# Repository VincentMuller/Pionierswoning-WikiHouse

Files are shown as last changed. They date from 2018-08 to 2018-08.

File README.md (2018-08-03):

# Pionierswoning-WikiHouse
First built WikiHouse as a test and showcase (finished feb. 2018) for the 20 WikiHouses project in Almere, Netherlands.
Started with the WREN system (as used in the MicroHouse) and changed it to a new system called SWIFT. Where WREN has a maximum span at 3,6 m is the span of SWIFT to 4,8 m. (WREN is more flexible for making window and door openings, SWIFT is more flexible in interior space) 

The files are updated with minor changes to (version 2) the WikiHouse chassis of the Pionierswoning, containing:
- Manual (pdf) with instructions how to build,
- CAD file (dxf) including all the parts for CNC-cutting,
- 3d Sketchup files (skp), including finishing materials inside and outside,
- Pictures of the construction as an extra help
- Calculations of the structural engineer
- And may be more to come later...

VERY IMPORTANT:
Find a structural engineer to do or check the calculations for fitting to local circumstances, laws and regulations.
Building this house is always on your own responsibility! 

Terms of use

By downloading these files or information you agree to the following terms and conditions.

Information is shared without any kind of warranty or guarantee All Information is provided ‘as is’. No representations or warranties express or implied are made regarding the Wikihouse Info, its accuracy, completeness, functionality or fitness for a particular use in a particular location.

You are solely responsible for the use of the information By using this information you assume full responsibility for any loss resulting from use or inability to use the Wikihouse Info, and forever releases WikiHouse Foundation or other WikiHouse users from any liability for such loss; including but not limited to loss of profits, goodwill or assets.

You are responsible for meeting local codes and legislation Users must satisfy themselves regarding the application of statutory requirements, local building regulations, codes, insurance certification or other requirements or recommendations relevant to the location where and materials with which they plan to build. Where required you should always seek the advice of a relevant qualified professional.

You are responsible for using the information in a safe way Users are responsible for ensuring that information they use or cause to be used is used in a way which is safe, and is not likely to cause harm during or after manufacturing, construction, use or disassembly.

Creative Commons License

<br />This work is licensed under a <a rel="license" href="http://creativecommons.org/licenses/by-sa/4.0/">Creative Commons Attribution-ShareAlike 4.0 International License</a>.

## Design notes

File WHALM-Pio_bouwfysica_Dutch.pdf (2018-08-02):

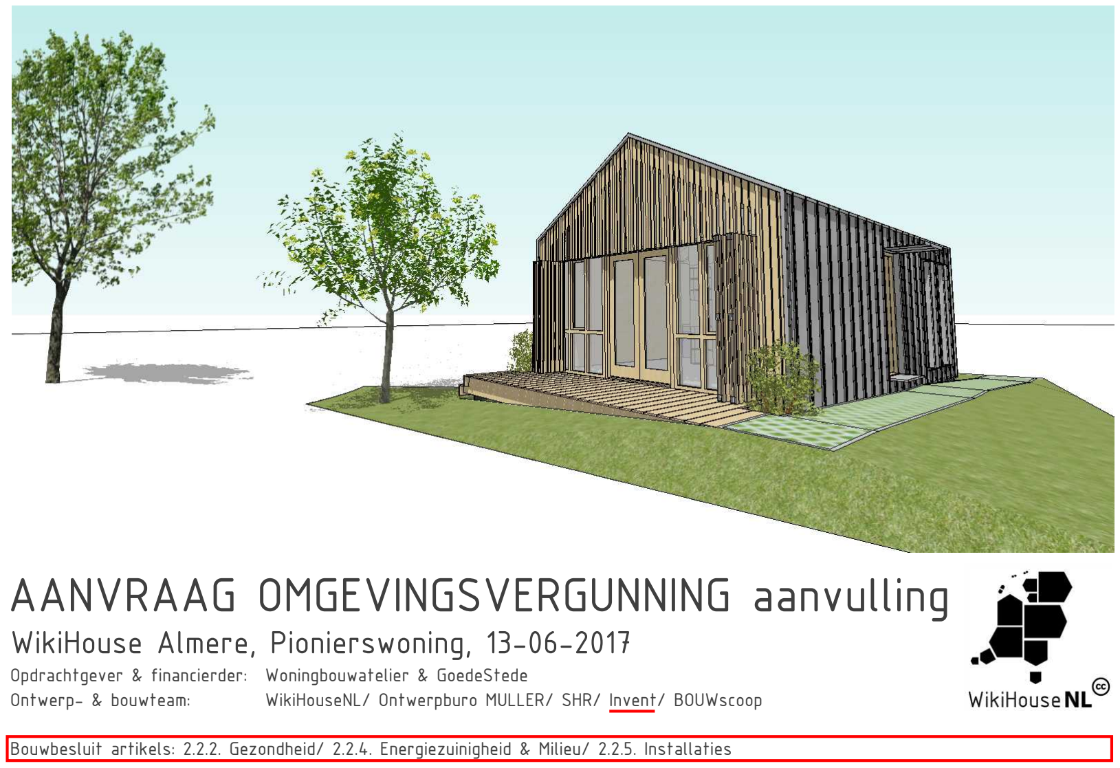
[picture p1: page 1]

# WikiHouse Almere, Pionierswoning, 13-06-2017

### Opdrachtgever & financierder: Woningbouwatelier & GoedeStede

Ontwerp- & bouwteam: | WikiHouseNL/ Ontwerpburo MULLER/ SHR/ Invent/ BOUWscoop

Bouwbesluit artikels: 2.2.2. Gezondheid/ 2.2.4. Energiezuinigheid & Milieu/ 2.2.5. Installaties

# AANVRAAG OMGEVINGSVERGUNNING aanvulling

## MEMO

Projectnummer: 16-526 | Projectnaam: WikiHouse Almere
Datum: 13 juni 2017 | Opsteller(s): E. Giesen
Onderwerp | : Verankering spant

### 1. Bouwfysische beoordeling

### 1.1. Toelichting

In onderstaande detailtekening is de verankering van de spanten zichtbaar door de vloerplaat op de HE140A funderingsbalk. Om te beoordelen of de bevestiging van de ankers condensatieproblemen kunnen veroorzaken is het detail in een 3D model uitgewerkt en doorgerekend (Trisco software). De afwerking van zowel de buitenzijde als de binnenzijde is hierbij achterwege gelaten, deze hebben geen invloed op de berekening van de f-factor (temperatuurfactor).

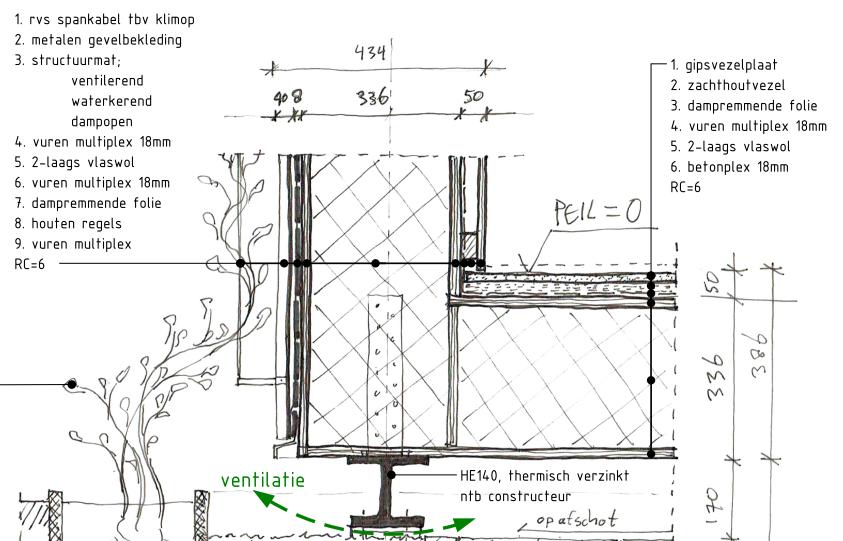
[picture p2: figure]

- Voor dit detail is een f-factor bepaald van 0,918. Dit voldoet aan het Bouwbesluit.

## MEMO

Projectnummer: 16-526 | Projectnaam: WikiHouse Almere
Datum: 13 juni 2017 | Opsteller(s): E. Giesen

### 1.2. Rekenresultaten Trisco

TRISCO - Rekenresultaten

TRISCO gegevensbestand: Detail verankering 20170613.trc

Aantal knooppunten = 1563504
Warmtedivergentie voor totaal object = 0.000852355
Warmtedivergentie voor meest nadelige knoop = 0.16967
Klr. Type | Naam | tmin | X | Y | Z | tmax | X | Y | Z
| | | [°C] | | | | [°C] | | | _
11 | MATERIAL | stainless steel | 0.06 | 61 | 15 | 100 | 3.37 | 71 | 71 | 42
13 | MATERIAL | steel | 0.02 | 77 | 1 | 0 | 0.07 | 58 | 26 | 27
41 | MATERIAL | PVC rigid | 14.80 | 127 | 81 | 57 | 19.65 | 128 | 114 | 122
60 | MATERIAL | EPDM | 0.02 | 35 | 27 | 0 | 0.14 | 58 | 29 | 27
131 | MATERIAL | insulation 0.04 | 0.01 | 11 | 39 | 2 | 19.35 | 117 | 114 | 0
137 | MATERIAL | cement-bonded p | 0.00 | 11 | 29 | 120 | 0.70 | 64 | 39 | 41
139 | MATERIAL | plywood 700 kg/ | 0.00 | 1 | 29 | 2 | 19.63 | 127 | 114 | 122
145 | MATERIAL | gypsum 1200 kg/ | 17.87 | 128 | 94 | 65 | 19.70 | 142 | 102 | 122
155 | MATERIAL | insulation 0.04 | 14.83 | 129 | 82 | 65 | 19.63 | 142 | 94 | 122
170 | BC_SIMPL | exterior | 0.00 | 1 | 29 | 2 | 0.18 | 1 | 114 | 50
174 | BC_SIMPL | interior (norma | 18.36 | 128 | 102 | 56 | 19.70 | 142 | 102 | 122
Klr. Type | Naam | ta | Flux in | Flux uit
| | | [°C] | | [W] | | [W]
170 | BC_SIMPL | exterior | 0.00 | 1.96
174 | BC_SIMPL | interior (norma | 1.96 | 0.00

Temperatuurfactor (EN ISO 10211) = 0.918
hi = 7.70 W/(m².K)
Rsi = 0.13 m².K/W
Oppervlaktecondensatie als RV > 90 % (bij 20.00°C)

## MEMO

Projectnummer: 16-526 | Projectnaam: WikiHouse Almere
Datum: 13 juni 2017 | Opsteller(s): E. Giesen

### 1.3. Afbeeldingen simulatiemodel

Afbeelding 1. Zijaanzicht materiaal en ʎ-waarden [2D]

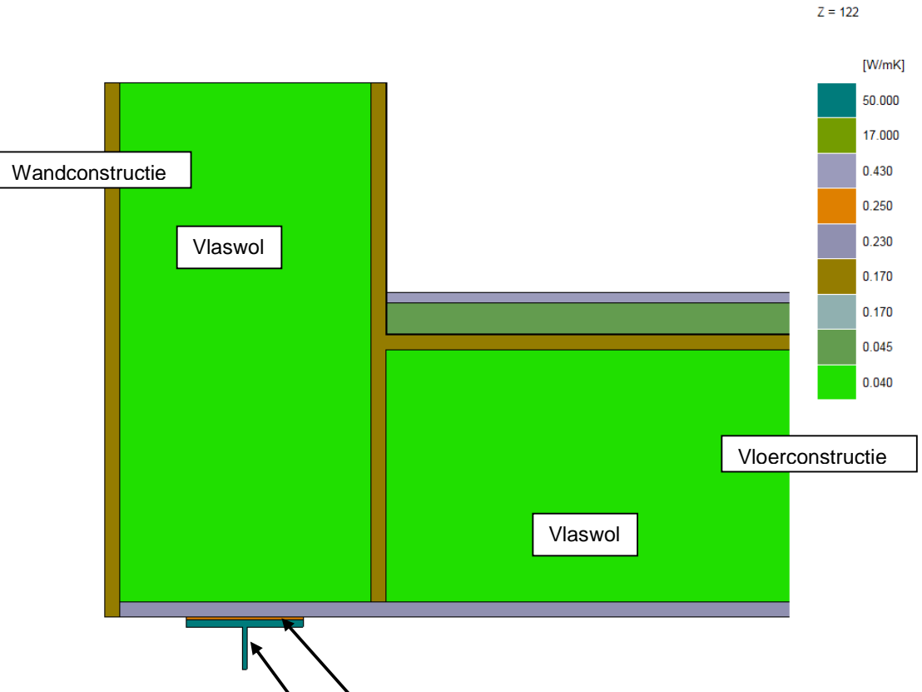
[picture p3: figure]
Vlaswol; Wandconstructie; Vloerconstructie

HE140A balk
(deels)

Neopreen

## MEMO

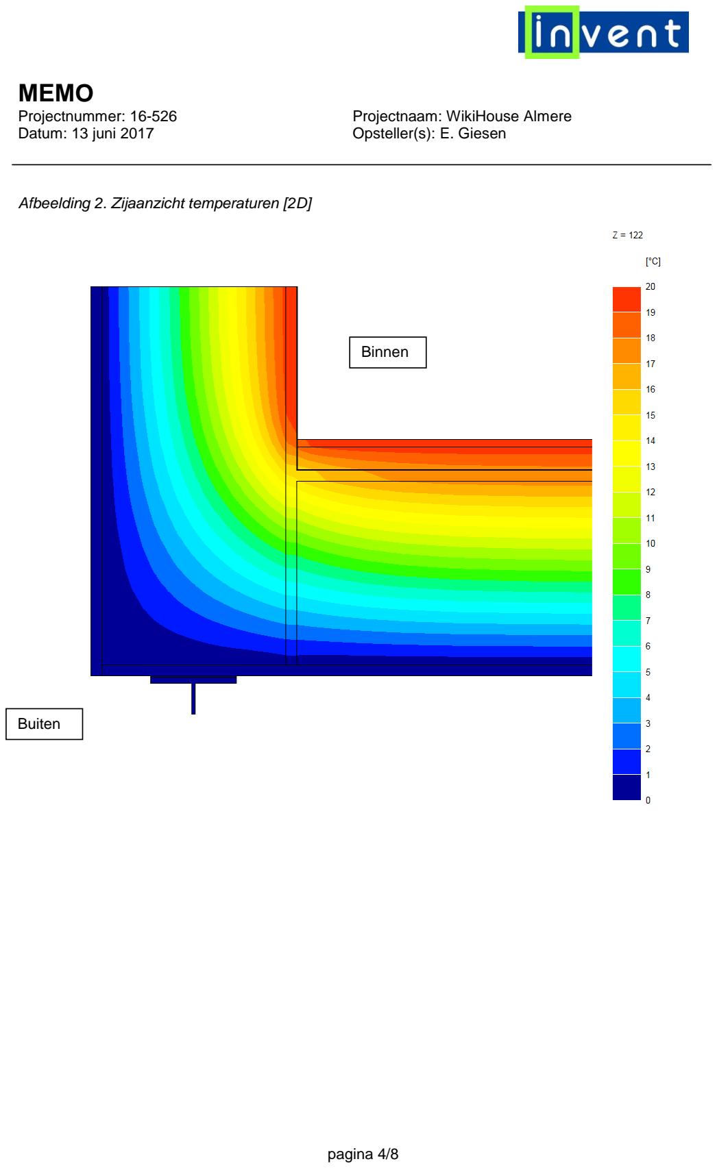
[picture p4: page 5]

Projectnummer: 16-526 | Projectnaam: WikiHouse Almere
Datum: 13 juni 2017 | Opsteller(s): E. Giesen

Afbeelding 2. Zijaanzicht temperaturen [2D]

Binnen

Buiten

## MEMO

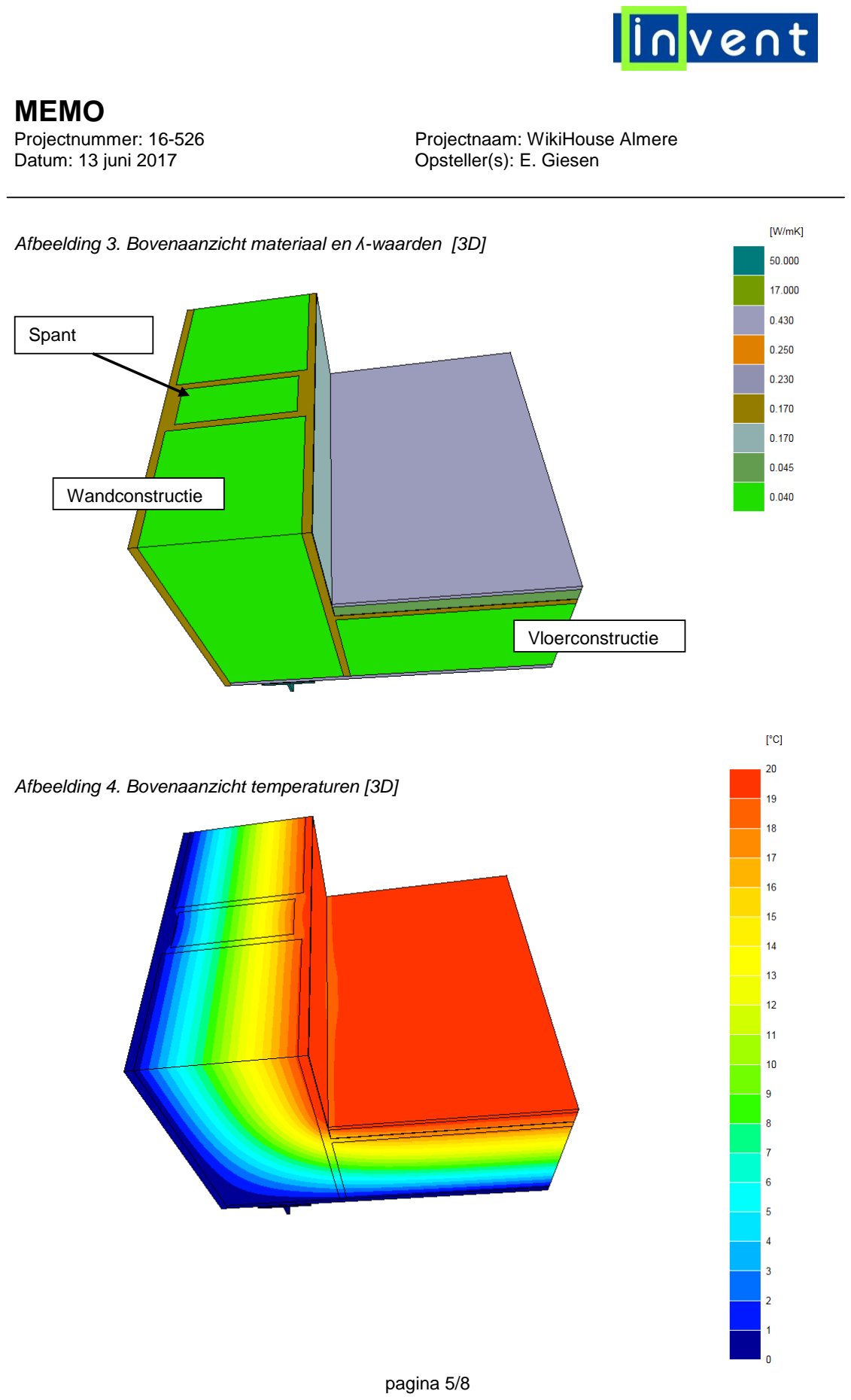
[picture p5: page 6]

Projectnummer: 16-526 | Projectnaam: WikiHouse Almere
Datum: 13 juni 2017 | Opsteller(s): E. Giesen

Afbeelding 3. Bovenaanzicht materiaal en ʎ-waarden [3D]

Afbeelding 4. Bovenaanzicht temperaturen [3D]

Spant

Wandconstructie

Vloerconstructie

## MEMO

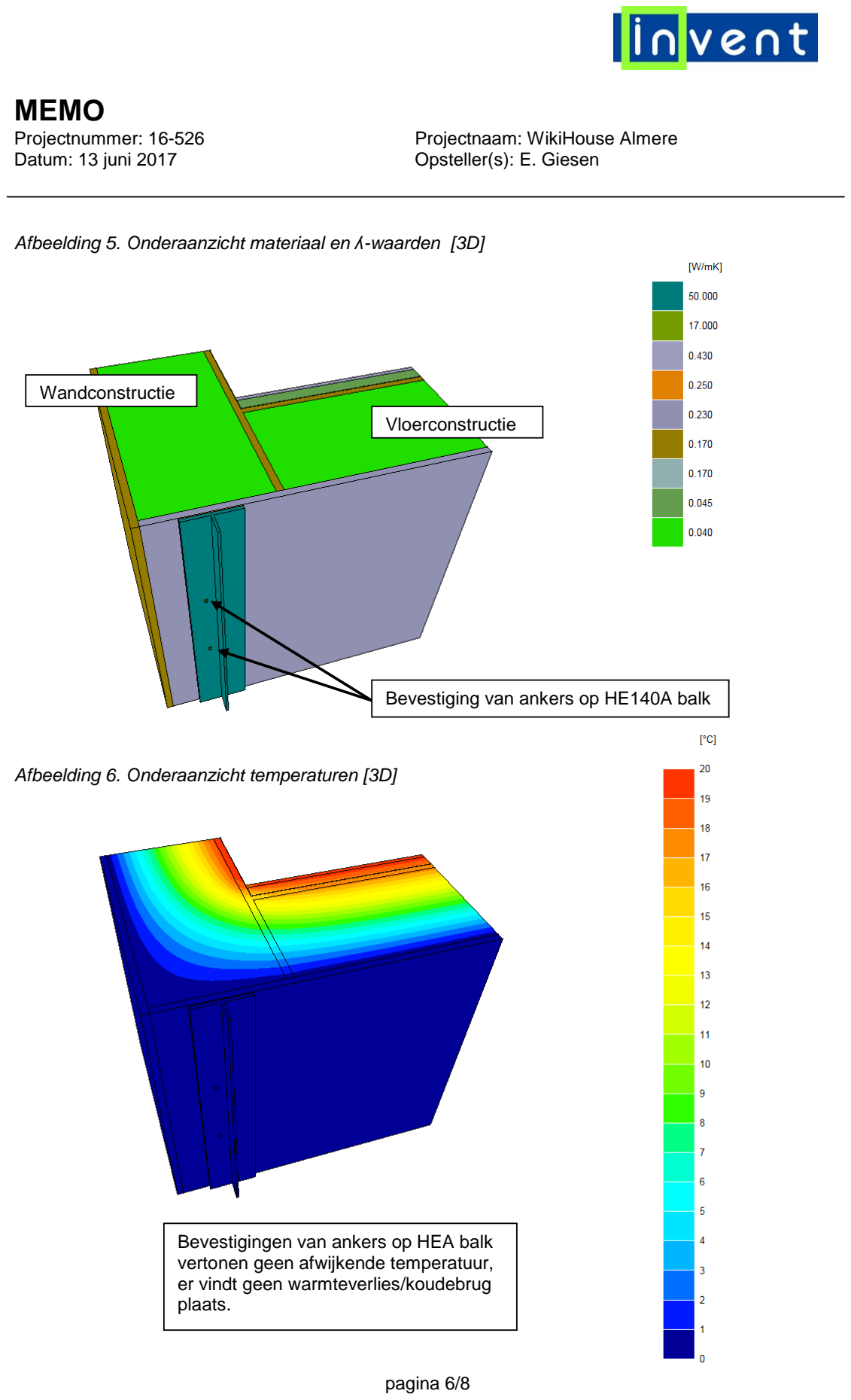
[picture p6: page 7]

Projectnummer: 16-526 | Projectnaam: WikiHouse Almere
Datum: 13 juni 2017 | Opsteller(s): E. Giesen

Afbeelding 5. Onderaanzicht materiaal en ʎ-waarden [3D]

Afbeelding 6. Onderaanzicht temperaturen [3D]

Bevestiging van ankers op HE140A balk

Bevestigingen van ankers op HEA balk vertonen geen afwijkende temperatuur, er vindt geen warmteverlies/koudebrug plaats.

Wandconstructie

Vloerconstructie

## MEMO

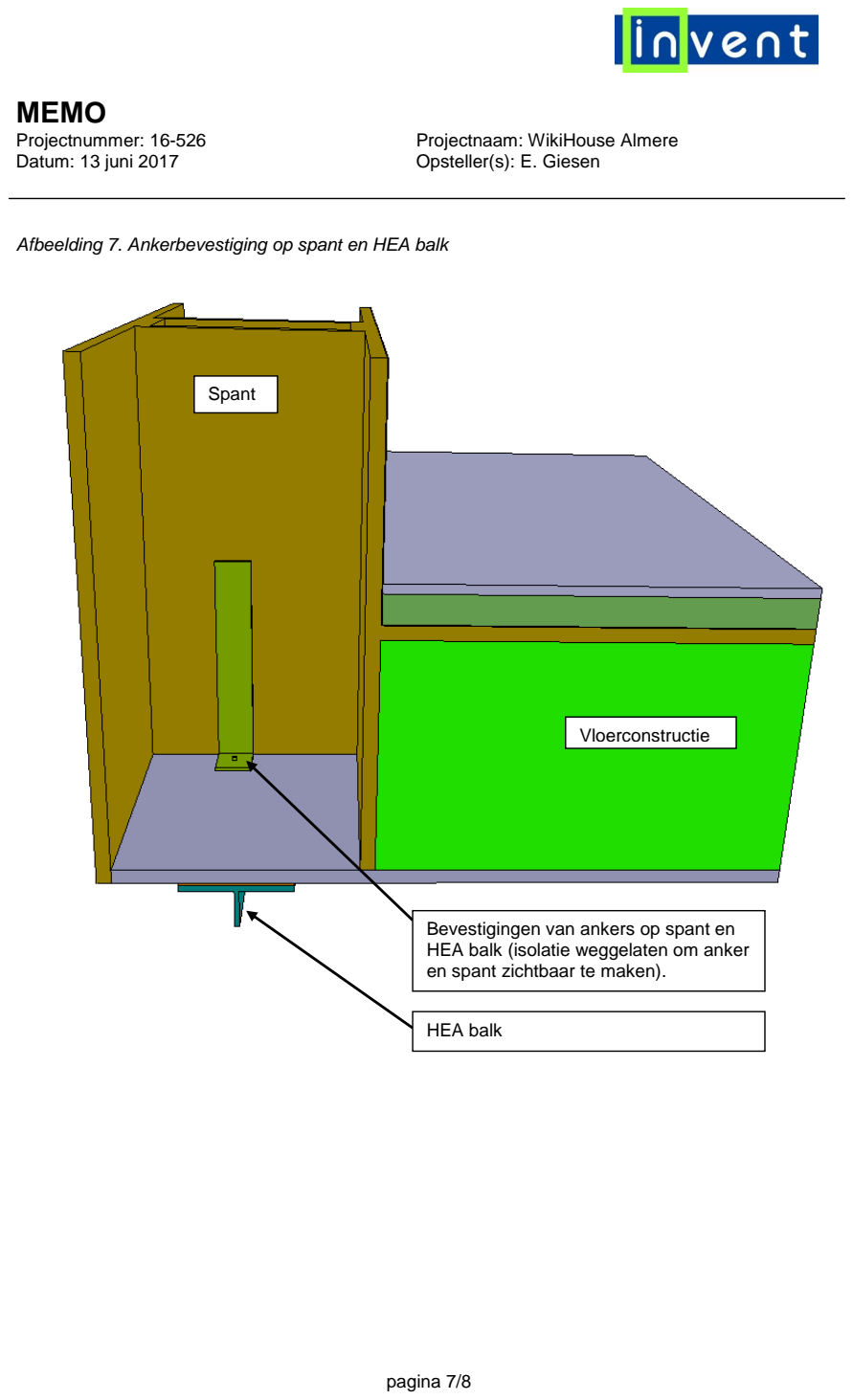
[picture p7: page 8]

Projectnummer: 16-526 | Projectnaam: WikiHouse Almere
Datum: 13 juni 2017 | Opsteller(s): E. Giesen

Afbeelding 7. Ankerbevestiging op spant en HEA balk

Bevestigingen van ankers op spant en HEA balk (isolatie weggelaten om anker en spant zichtbaar te maken).

HEA balk

Spant

Vloerconstructie

## MEMO

Projectnummer: 16-526 | Projectnaam: WikiHouse Almere
Datum: 13 juni 2017 | Opsteller(s): E. Giesen

Afbeelding 8. Bovenaanzicht ankerbevestiging op spant

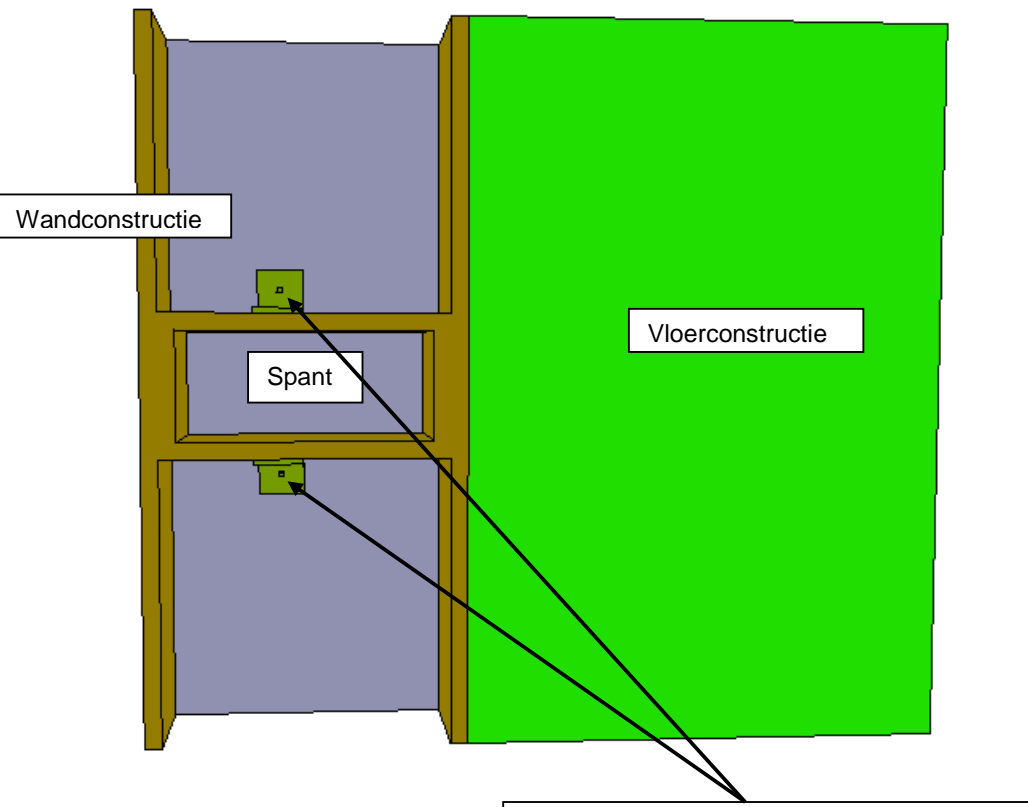
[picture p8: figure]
Spant; Vloerconstructie; Wandconstructie

Bevestigingen van ankers aan beide zijde op het spant (isolatie weggelaten om ankers en spant zichtbaar te maken).

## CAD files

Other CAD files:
Whalm-Pio_v2_CNC-parts.dxf

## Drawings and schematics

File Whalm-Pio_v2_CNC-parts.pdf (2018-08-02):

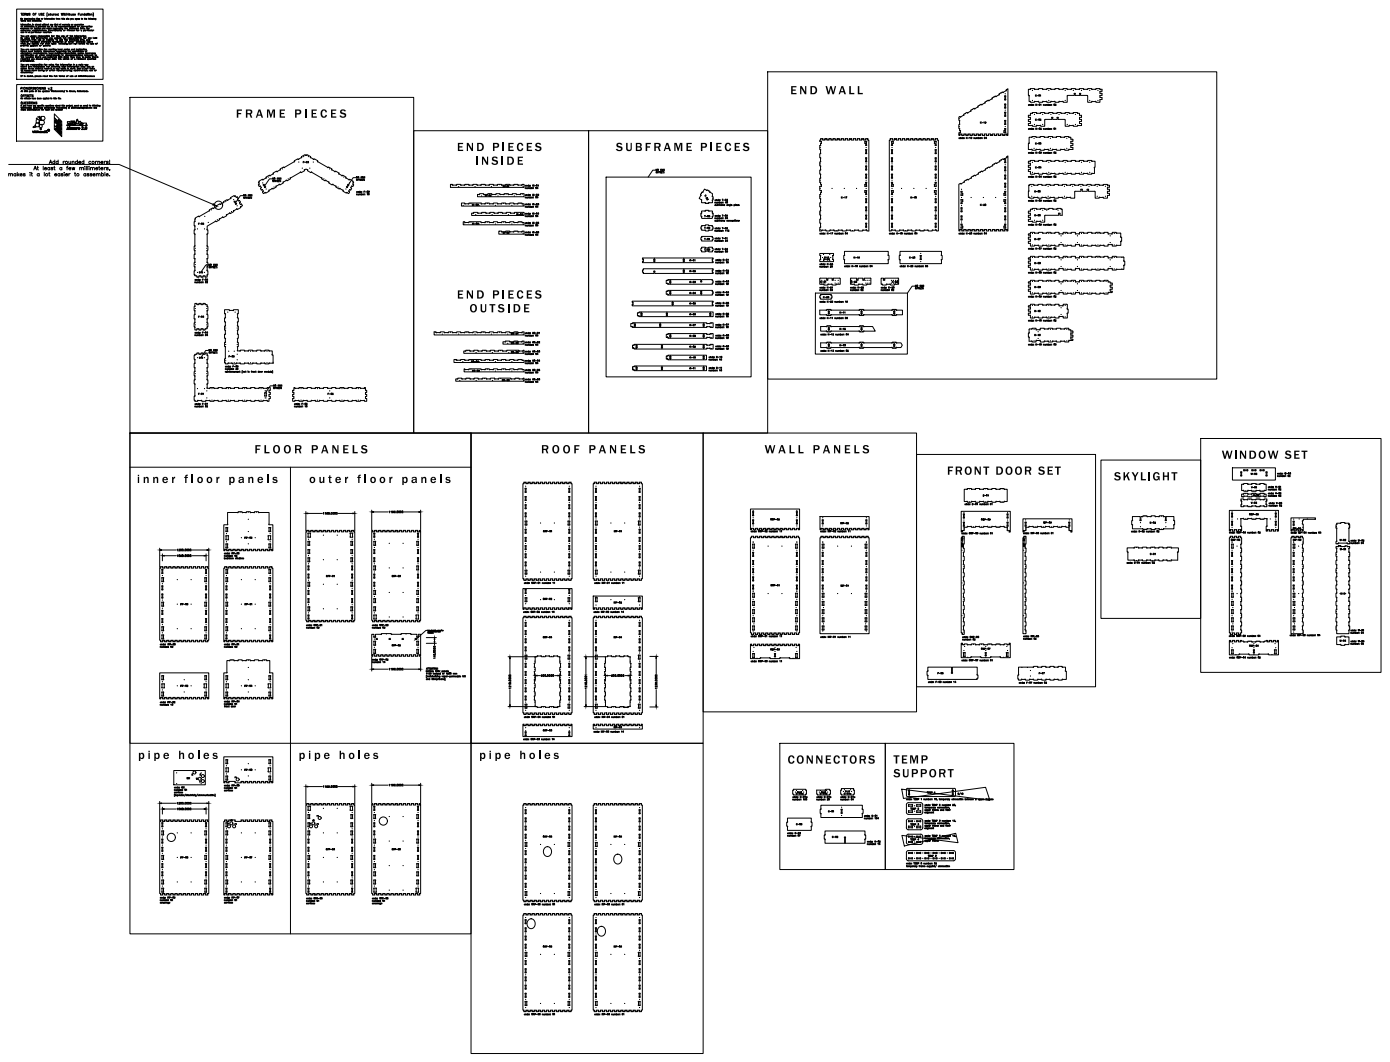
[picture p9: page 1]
FLOOR PANELS; ROOF PANELS; WALL PANELS CONNECTORS; SKYLIGHT; WINDOW SET FRONT DOOR SET SUBFRAME PIECES FRAME PIECES; END PIECES INSIDE inner floor panels; outer floor panels; TEMP SUPPORT END WALL pipe holes; pipe holes; pipe holes END PIECES OUTSIDE ‘
